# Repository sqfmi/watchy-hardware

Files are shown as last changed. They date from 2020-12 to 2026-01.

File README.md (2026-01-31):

# Watchy - Hardware Source Files

Watchy

**Buy Watchy from [The Pi Hut](https://thepihut.com/collections/sqfmi), [Crowd Supply](https://www.crowdsupply.com/sqfmi/watchy), and [Mouser](https://www.mouser.com/ProductDetail/SQFMI/SQFMI-WATCHY-10?qs=DRkmTr78QARN9VSJRzqRxw%3D%3D)!**

[**Watchy Case & Accessories**](https://shop.sqfmi.com)

Visit [**https://watchy.sqfmi.com**](https://watchy.sqfmi.com) to get started!

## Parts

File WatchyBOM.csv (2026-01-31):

Id | Designator | Footprint | Quantity | Designation | Supplier and ref
1 | Q3 | SOT-23 | 1 | AO3400A
2 | L2 | L_Taiyo-Yuden_NR-40xx | 1 | 47uH 0.5A
3 | D5,D4,D3 | D_SOD-123 | 3 | MBR0530
4 | R17 | R_0402_1005Metric | 1 | 2.2
5 | C21,C20 | C_0603_1608Metric | 2 | 4.7uF/50V
6 | U3 | SOT-23-5 | 1 | TP4054
7 | R16 | R_0402_1005Metric | 1 | 1M
8 | J1 | 1.25T-2PWT (Molex 532610271) | 1 | Battery
9 | J3 | 24_Pins_0.5mm_Pitch_ZIF_Connector_UP | 1 | FPC24(0.5MM)
10 | M1 | Motor_Header | 1 | Vibration_Motor
11 | J2 | USB_Micro-B | 1 | Micro USB
12 | G*** | sqfmi_duck | 1 | LOGO
13 | C29,C25,C27,C22,C23,C24,C28,C26 | C_0402_1005Metric | 8 | 1uF/50V
14 | C3,C2,C15,C4 | C_0402_1005Metric | 4 | 1uF
15 | R4,R2,R15,R8,R11,R6,R19,R7,R10 | R_0402_1005Metric | 9 | 100K
16 | Y2 | Crystal_SMD_2520-4Pin_2.5x2.0mm | 1 | 40MHz
17 | TP5 | TestPoint_Pad_D1.0mm | 1 | GND
18 | SW1 | EVQPUC | 1 | BTN2
19 | C6,C5,C11,C14,C12,C13 | C_0402_1005Metric | 6 | 100nF
20 | C10,C1 | C_0402_1005Metric | 2 | 10uF
21 | R13 | R_0402_1005Metric | 1 | 1K
22 | L1 | L_0402_1005Metric | 1 | TBD
23 | Q2 | SOT-23 | 1 | S8050
24 | U4 | QFN-56-1EP_7x7mm_P0.4mm_EP5.6x5.6mm | 1 | ESP32-S3
25 | R18,R3,R1,R20 | R_0402_1005Metric | 4 | 10K
26 | R5,R14 | R_0402_1005Metric | 2 | 51K
27 | TP6 | TestPoint_Pad_D1.0mm | 1 | SCL
28 | SW2 | EVQPUC | 1 | BTN1
29 | TP2 | TestPoint_Pad_D1.0mm | 1 | RX
30 | C9,C7 | C_0402_1005Metric | 2 | TBD
31 | Q1 | SOT-23 | 1 | CJ2301
32 | U6 | LGA-12_2x2mm_P0.5mm | 1 | BMA423
33 | AE1 | SWRA117D | 1 | Antenna_Chip
34 | TP1 | TestPoint_Pad_D1.0mm | 1 | TX
35 | C16,C19 | C_0402_1005Metric | 2 | 22pF
36 | SW3 | EVQPUC | 1 | BTN3
37 | U2 | SOT-23-5 | 1 | RT908033
38 | TP7 | TestPoint_Pad_D1.0mm | 1 | SDA
39 | R9 | R_0402_1005Metric | 1 | 360K
40 | D2 | D_SOD-123F | 1 | 1N4001
41 | C18,C17 | C_0402_1005Metric | 2 | 18pF
42 | TP3 | TestPoint_Pad_D1.0mm | 1 | BOOT
43 | U5 | SOT-666 | 1 | USBLC6-2P6
44 | TP4 | TestPoint_Pad_D1.0mm | 1 | 3V3
45 | R12 | R_0402_1005Metric | 1 | TBD
46 | SW4 | EVQPUC | 1 | BTN4
47 | U1 | SR2HARU | 1 | SR2HARU
48 | D1 | D_SOD-123 | 1 | MBR0530
49 | Y1 | Crystal_SMD_2012-2Pin_2.0x1.2mm | 1 | 32.768KHz

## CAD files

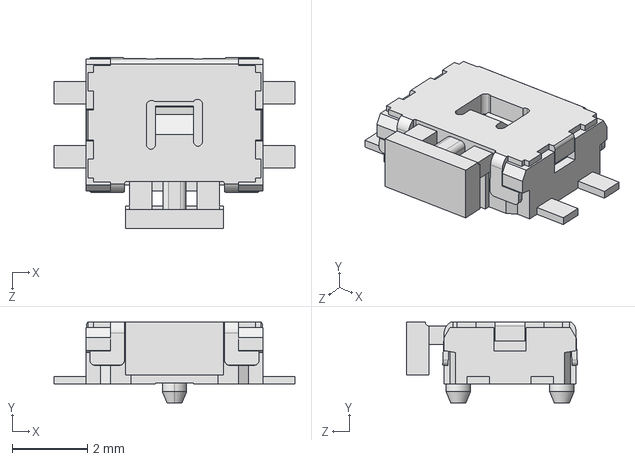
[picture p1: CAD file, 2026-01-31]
3D/EVQPU-LC-02K.STEP
6.40 x 2.15 x 4.54 mm

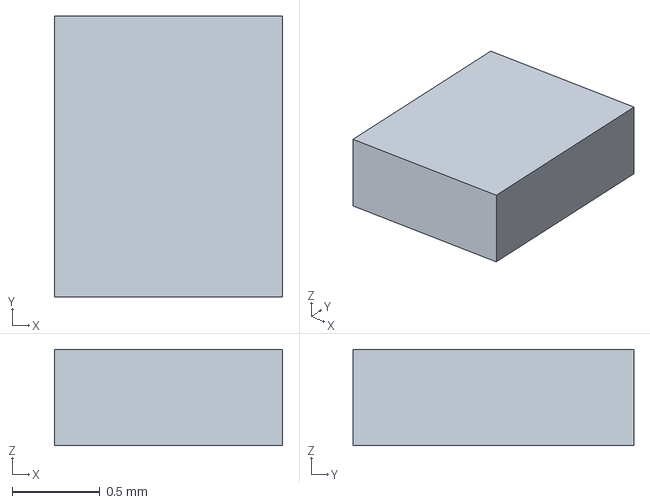
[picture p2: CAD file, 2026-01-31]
3D/UDFN6_16x13.step
1.30 x 1.60 x 0.55 mm

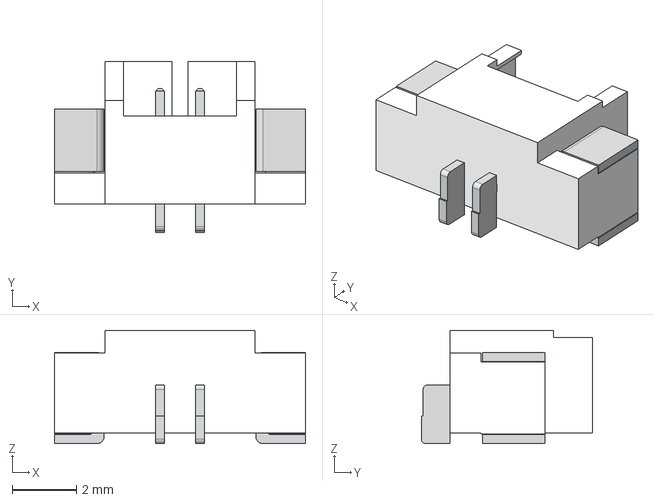
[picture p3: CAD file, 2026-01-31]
3D/JST - SMD (R) - 2Pin - 1.25mm.step
7.83 x 5.35 x 3.53 mm

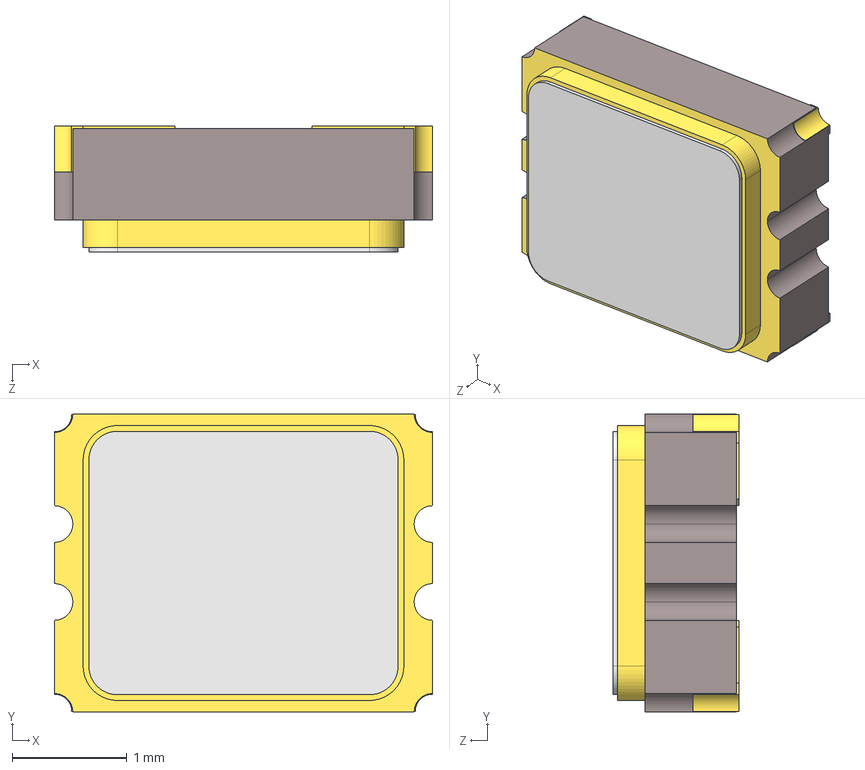
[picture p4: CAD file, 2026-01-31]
3D/Crystal_4pin_2520.STEP
3.30 x 2.60 x 1.10 mm
ASTX_Pad
ASTX_Pad001
ASTX_Pad002
ASTX_ComponentPads

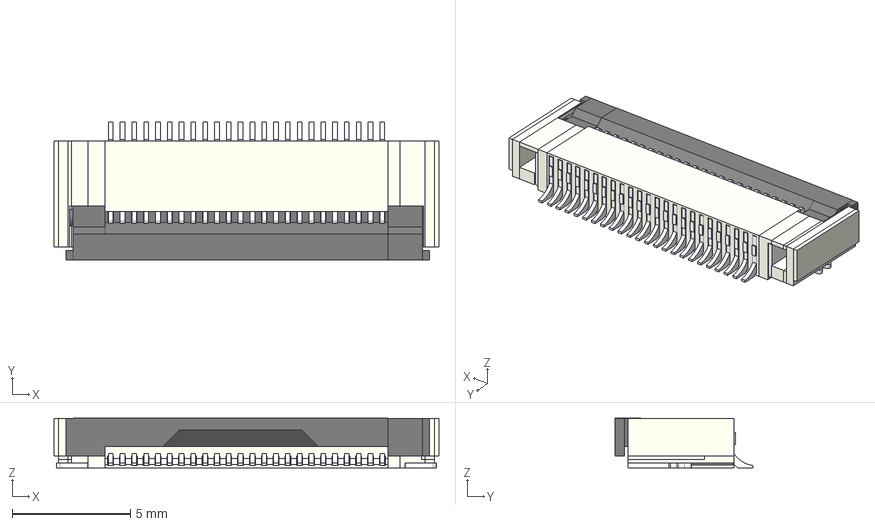
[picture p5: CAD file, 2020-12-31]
3D/FPC-24.stp
16.3 x 5.85 x 2.11 mm

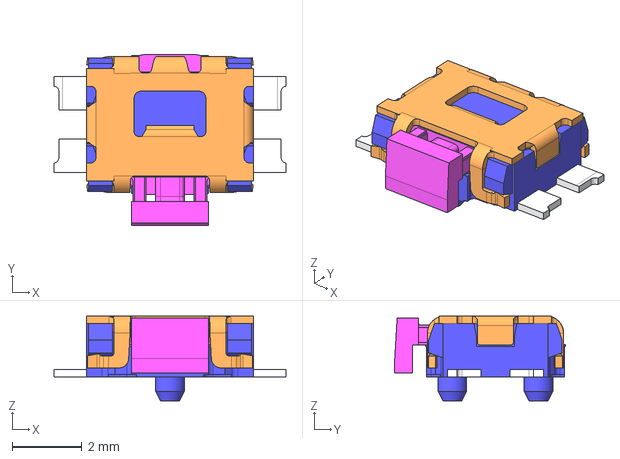
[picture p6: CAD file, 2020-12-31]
3D/Button.step
6.65 x 4.89 x 2.43 mm

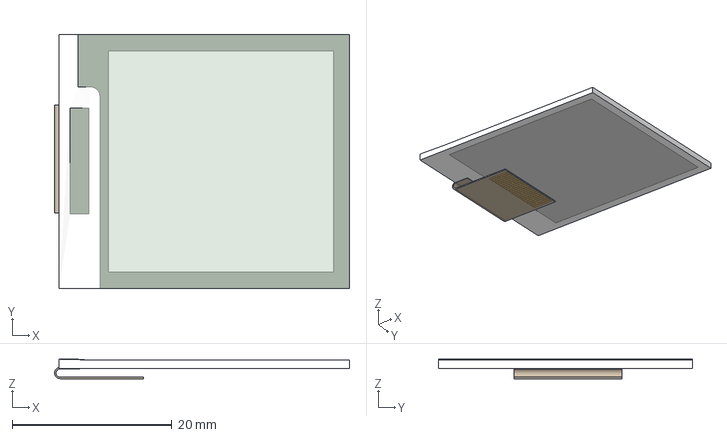
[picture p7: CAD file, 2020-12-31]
3D/Display.step
36.9 x 31.8 x 2.45 mm

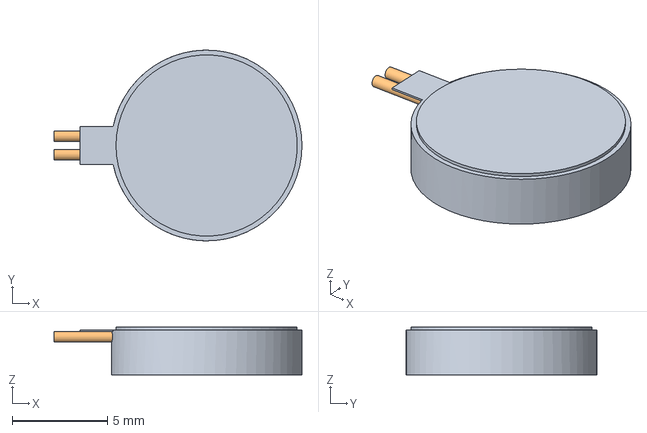
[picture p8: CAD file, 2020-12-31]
3D/PagerMotor.STEP
13.0 x 10.00 x 2.50 mm

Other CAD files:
3D/Battery402030.step

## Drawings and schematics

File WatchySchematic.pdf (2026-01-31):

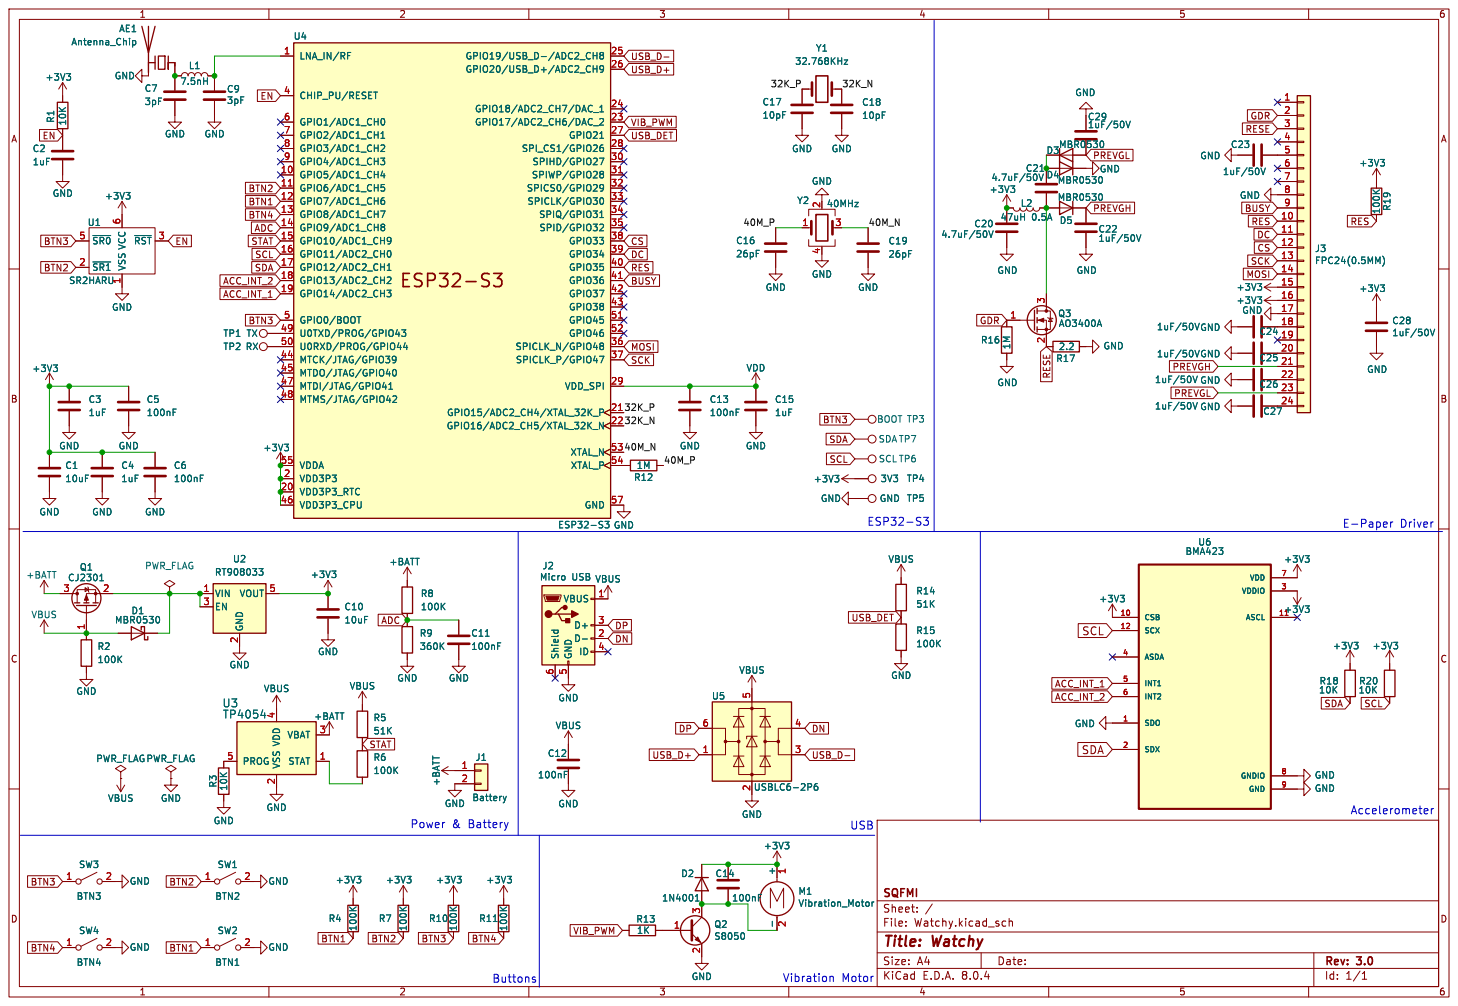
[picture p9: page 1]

File: Watchy.kicad_sch Sheet: / SQFMI GND

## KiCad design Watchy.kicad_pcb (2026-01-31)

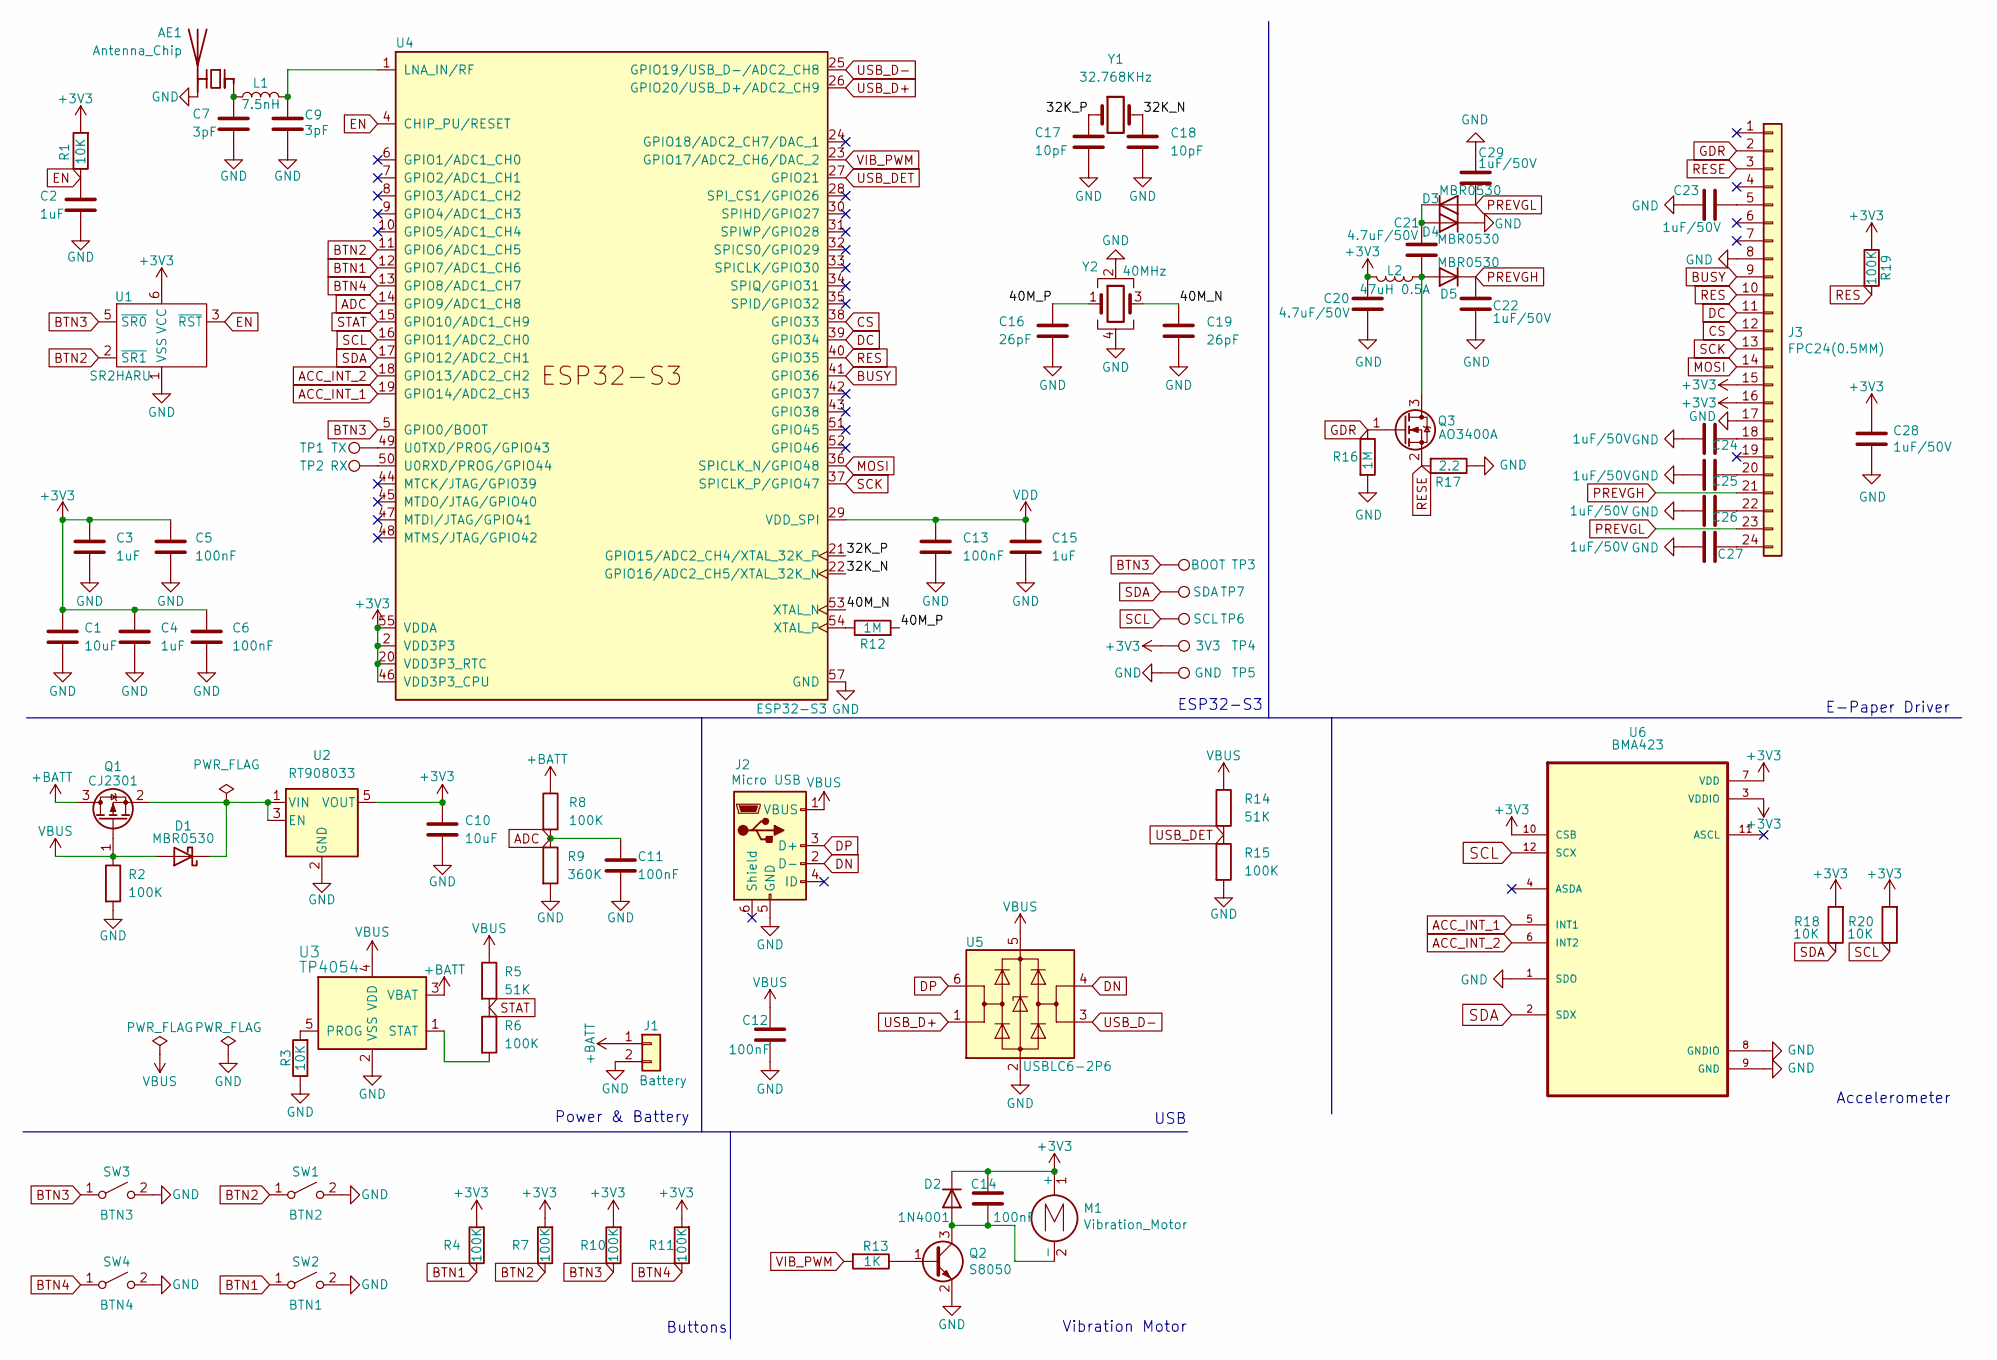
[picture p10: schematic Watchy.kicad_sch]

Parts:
AE1: Antenna_Chip; SWRA117D
C1, C10: 10uF; C_0402_1005Metric
C2, C3, C4, C15: 1uF; C_0402_1005Metric
C5, C6, C11, C12, C13, C14: 100nF; C_0402_1005Metric
C7, C9: 3pF; C_0402_1005Metric
C16, C19: 26pF; C_0402_1005Metric
C17, C18: 10pF; C_0402_1005Metric
C20, C21: 4.7uF/50V; C_0603_1608Metric
C22, C23, C24, C25, C26, C27, C28, C29: 1uF/50V; C_0402_1005Metric
D1, D3, D4, D5: MBR0530; D_SOD-123
D2: 1N4001; D_SOD-123F
J1: Battery; 1.25T-2PWT (Molex 532610271)
J2: Micro USB; USB_Micro-B
J3: FPC24(0.5MM); 24_Pins_0.5mm_Pitch_ZIF_Connector_UP
L1: 7.5nH; L_0402_1005Metric
L2: 47uH 0.5A; L_Taiyo-Yuden_NR-40xx
M1: Vibration_Motor; Motor_Header
Q1: CJ2301; SOT-23
Q2: S8050; SOT-23
Q3: AO3400A; SOT-23
R1, R3, R18, R20: 10K; R_0402_1005Metric
R2, R4, R6, R7, R8, R10, R11, R15, R19: 100K; R_0402_1005Metric
R5, R14: 51K; R_0402_1005Metric
R9: 360K; R_0402_1005Metric
R12, R16: 1M; R_0402_1005Metric
R13: 1K; R_0402_1005Metric
R17: 2.2; R_0402_1005Metric
SW1: BTN2; EVQPUC
SW2: BTN1; EVQPUC
SW3: BTN3; EVQPUC
SW4: BTN4; EVQPUC
TP1: TX; TestPoint_Pad_D1.0mm
TP2: RX; TestPoint_Pad_D1.0mm
TP3: BOOT; TestPoint_Pad_D1.0mm
TP4: 3V3; TestPoint_Pad_D1.0mm
TP5: GND; TestPoint_Pad_D1.0mm
TP6: SCL; TestPoint_Pad_D1.0mm
TP7: SDA; TestPoint_Pad_D1.0mm
U1: SR2HARU
U2: RT908033; SOT-23-5
U3: TP4054; SOT-23-5
U4: ESP32-S3; QFN-56-1EP_7x7mm_P0.4mm_EP5.6x5.6mm
U5: USBLC6-2P6; SOT-666
U6: BMA423; LGA-12_2x2mm_P0.5mm
Y1: 32.768KHz; Crystal_SMD_2012-2Pin_2.0x1.2mm
Y2: 40MHz; Crystal_SMD_2520-4Pin_2.5x2.0mm

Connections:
+3V3: C1.1, C3.1, C4.1, C5.1, C6.1, C10.1, C14.1, C20.1, C28.1, D2.1 (K), J3.15, J3.16, L2.2, M1.1 (+), R1.2, R4.2, R7.2, R10.2, R11.2, R18.2, R19.1, R20.2, TP4.1, U1.6 (VCC), U2.5 (VOUT), U4.2 (VDD3P3), U4.3 (VDD3P3), U4.20 (VDD3P3_RTC), U4.46 (VDD3P3_CPU), U4.55 (VDDA), U4.56 (VDDA), U6.3 (VDDIO), U6.7 (VDD), U6.10 (CSB); also elsewhere on the board
+BATT: J1.1, Q1.3 (D), R8.1, U3.3 (VBAT)
/32K_N: C18.1, U4.22 (GPIO16/ADC2_CH5/XTAL_32K_N), Y1.2
/32K_P: C17.1, U4.21 (GPIO15/ADC2_CH4/XTAL_32K_P), Y1.1
/40M_N: C19.1, U4.53 (XTAL_N), Y2.3
/40M_P: C16.1, R12.2, Y2.1
ACC_INT_1: U4.19 (GPIO14/ADC2_CH3), U6.5 (INT1)
ACC_INT_2: U4.18 (GPIO13/ADC2_CH2), U6.6 (INT2)
ADC: C11.1, R8.2, R9.1, U4.14 (GPIO9/ADC1_CH8)
BTN1: R4.1, SW2.1 (A), U4.12 (GPIO7/ADC1_CH6)
BTN2: R7.1, SW1.1 (A), U1.2 (~SR1), U4.11 (GPIO6/ADC1_CH5)
BTN3: R10.1, SW3.1 (A), TP3.1, U1.5 (~SR0), U4.5 (GPIO0/BOOT)
BTN4: R11.1, SW4.1 (A), U4.13 (GPIO8/ADC1_CH7)
BUSY: J3.9, U4.41 (GPIO36)
CS: J3.12, U4.38 (GPIO33)
DC: J3.11, U4.39 (GPIO34)
DN: J2.2 (D-), U5.4 (I/O2)
DP: J2.3 (D+), U5.6 (I/O1)
EN: C2.1, R1.1, U1.3 (~RST), U4.4 (CHIP_PU/RESET)
GDR: J3.2, Q3.1 (G), R16.1
GND: AE1.2 (PCB_Trace), C1.2, C2.2, C3.2, C4.2, C5.2, C6.2, C7.2, C9.2, C10.2, C11.2, C12.2, C13.2, C15.2, C16.2, C17.2, C18.2, C19.2, C20.2, C22.2, C23.2, C24.2, C25.2, C26.2, C27.2, C28.2, C29.1, D4.1 (K), J1.2, J2.5 (GND), J3.8, J3.17, Q2.2 (E), R2.2, R3.1, R9.2, R15.2, R16.2, R17.1, SW1.2 (B), SW2.2 (B), SW3.2 (B), SW4.2 (B), TP5.1, U1.1 (VSS), U2.2 (GND), U3.2 (VSS), U4.57 (GND), U5.2 (GND), U6.1 (SDO), U6.8 (GNDIO), U6.9 (GND), Y2.2, Y2.4; also elsewhere on the board
MOSI: J3.14, U4.36 (SPICLK_N/GPIO48)
unnamed: AE1.1 (FEED), C7.1, L1.1
unnamed: D1.1 (K), Q1.2 (S), U2.1 (VIN), U2.3 (EN)
unnamed: C14.2, D2.2 (A), M1.2 (-), Q2.3 (C)
unnamed: C21.1, D3.1 (K), D4.2 (A)
unnamed: C21.2, D5.2 (A), L2.1, Q3.3 (D)
unnamed: C23.1, J3.5
unnamed: C24.1, J3.18
unnamed: C25.1, J3.20
unnamed: C26.1, J3.22
unnamed: C27.1, J3.24
unnamed: Q2.1 (B), R13.1
unnamed: R3.2, U3.5 (PROG)
unnamed: R6.2, U3.1 (STAT)
unnamed: C9.1, L1.2, U4.1 (LNA_IN/RF)
unnamed: TP2.1, U4.50 (U0RXD/PROG/GPIO44)
unnamed: TP1.1, U4.49 (U0TXD/PROG/GPIO43)
unnamed: R12.1, U4.54 (XTAL_P)
PREVGH: C22.1, D5.1 (K), J3.21
PREVGL: C29.2, D3.2 (A), J3.23
RES: J3.10, R19.2, U4.40 (GPIO35)
RESE: J3.3, Q3.2 (S), R17.2
SCK: J3.13, U4.37 (SPICLK_P/GPIO47)
SCL: R20.1, TP6.1, U4.16 (GPIO11/ADC2_CH0), U6.12 (SCX)
SDA: R18.1, TP7.1, U4.17 (GPIO12/ADC2_CH1), U6.2 (SDX)
STAT: R5.2, R6.1, U4.15 (GPIO10/ADC1_CH9)
USB_D+: U4.26 (GPIO20/USB_D+/ADC2_CH9), U5.1 (I/O1)
USB_D-: U4.25 (GPIO19/USB_D-/ADC2_CH8), U5.3 (I/O2)
USB_DET: R14.2, R15.1, U4.27 (GPIO21)
VBUS: C12.1, D1.2 (A), J2.1 (VBUS), Q1.1 (G), R2.1, R5.1, R14.1, U3.4 (VDD), U5.5 (VBUS)
VDD: C13.1, C15.1, U4.29 (VDD_SPI)
VIB_PWM: R13.2, U4.23 (GPIO17/ADC2_CH6/DAC_2)

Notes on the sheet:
Vibration Motor
Buttons
E-Paper Driver
Accelerometer
ESP32-S3
USB
Power & Battery

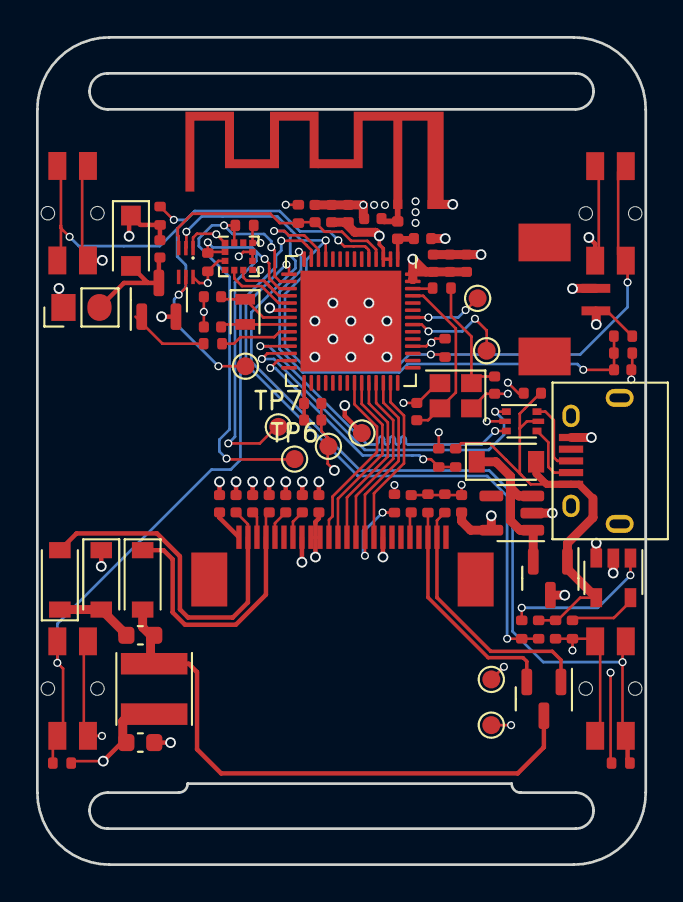
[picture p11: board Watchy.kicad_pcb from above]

Board: 4 copper layers, 33.8 x 46.0 mm, 84 parts (0 on the bottom side), 53 nets.

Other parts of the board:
TP4#2: 3V3; TestPoint_Pad_D1.0mm
TP5#2: GND; TestPoint_Pad_D1.0mm

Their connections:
+3V3: TP4#2.1; also elsewhere on the board
GND: TP5#2.1; also elsewhere on the board

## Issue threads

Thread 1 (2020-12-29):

Missing 3D models?

jdarpinian, 2020-12-29:
I'm new to kicad, so forgive me if I'm missing something, but it seems like the project references at least one 3D model that's not included in the repo here, ${KIPRJMOD}/3D/PagerMotor.STEP. Also the latest kicad libraries (https://github.com/kicad/kicad-packages3d) do not include ${KISYS3DMOD}/Button_Switch_SMD.3dshapes/SKSCLB.STEP or Capacitors_SMD.3dshapes/C_0603.wrl among others. Do I need to install extra libraries, or use a different version of kicad (currently 5.1.9)?

sqfmi, 2020-12-31:
Updated project to reference correct models, should work with current version of KiCad

jdarpinian, 2021-01-01:
Awesome! Thanks!

Closed 2021-01-01.

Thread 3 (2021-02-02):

Missing 32KHz oscillator for Low-Power BLE connectivity

LeonMatthes, 2021-02-02:
As mentioned in [this issue](https://github.com/espressif/esp-idf/issues/947 ), BLE with light sleep on the ESP32 is currently only supported with the use of an external 32KHz oscillator.

Unfortunately, Watchy currently does not have this, which is going to make it very difficult to maintain a true low power Bluetooth connectivity to a smartphone. For me this is a major use case for a smart watch...

Even more unfortunate is that the RTC can provide the exact waveform needed at its 32KHz output pin, however, it's not connected to the right pin of the ESP (GPIO 32_XP). And the pin is already used for BTN_3. (At least I think, I'm not a Hardware expert).

Maybe this could be fixed in a new revision of the Watchy hardware (perhaps even in the crowd supply campaign :pray: ).

m986883511, 2021-02-08:
I also have this problem，我用的的是现成的ESP32-WRROOM-32模块，没法加32k的晶振，这个是个不错的想法，希望得到乐鑫的解答。

LeonMatthes, 2021-02-10:
After looking at the ESP32 Hardware reference manual, I just wanted to add that the input pin for the 32KHz waveform might have to be the 32_XN (IO33) pin, and 32_XP might need to be connected to ground through a capacitor, but I'm not certain on this.
It would just be amazing to see the 2mA power consumption with BLE active that can be seen in the prior thread!

Jan-NiklasB, 2021-03-25:
If the devs don't see any problems with the changes, this should fix it: #5

Jan-NiklasB, 2021-03-25:
NVM, have to do it over again, LeonMatthes is right with the assumption that the source has to be connected to 32K_X**N** and a capacitor has to be placed between GND and 32K_XP...

sqfmi, 2021-03-25:
@Jan-NiklasB also it is recommended the signal amplitude be 0.6 < Vpp < VDD. We actually have a layout we're testing before we publish, so this might save you some time...

LeonMatthes, 2021-12-16:
From recent discussion on Discord it seems this is now part of the new board design.
@sqfmi can you confirm?
And has anyone tried it? Can you keep BLE active during light sleep?

This might seriously be a reason for me to get a newer version.

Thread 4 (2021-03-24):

[Feature request] Pulse-oxymeter

Jan-NiklasB, 2021-03-24:
Hey guys,

I just stumbled over this project looking for a possible smart watch candidate to buy (should be OHW / OS).
I'm a fan of the ESP32 uC, so this project has a greate potetial in my opinion, but looking at the most other smart watches out there I'm personally missing a pulse-oxymeter (heart rate + SpO2 sensor).

So I want to suggest include such sensor in a future version of this project.
Those sensors are getting more and more tiny, so I guess such a chp could may be added to the PCB.

I would be interested in your thoughts about this idea.

Greetings
Jan-Niklas

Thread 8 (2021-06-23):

[Feature Request] NFC

aceggroll, 2021-06-23:
For next revision, can you add NFC components. (eg https://www.nxp.com/docs/en/nxp/data-sheets/PN532_C1.pdf)
Could then use Watchy with other NFC devices, eg  https://arduinogetstarted.com/tutorials/arduino-rfid-nfc-door-lock-system
Happy to be first to sign up on CrowdSupply!

danShumway, 2021-07-22:
I'll also throw out a vote for NFC. Would really open some doors for using the device in interesting ways I think, considering how cheap NFC tags are.

I'm sticking tags up around my house for triggering actions with my phone, but I don't always carry my phone. I will almost always have a watch on though, so Watchy would be just completely perfect for something like this.

adapt-L, 2024-08-04:
It would be cool if watchy had this capability. But what antenna would this require? I was looking at how Flipper Zero implemented NFC and RFID, and it seems like it might require a large circuit board to act as the antenna.

adapt-L, 2024-08-04:
But yeah, it would be really nice to use watchy as a wireless-swiss-army-knife like Flipper Zero (You can use it to clone your NFC/RFID cards). It already has the hardware to compete with products like https://dstike.com/products/dstike-deauther-watch-v3s

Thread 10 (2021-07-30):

[Feature request] Beeps/sound

denizzzka, 2021-07-30:

adapt-L, 2024-08-04:
I just got the new one, and it has a vibration motor if that meets your needs

denizzzka, 2024-08-04:
Oh, finally I waited! :-)

Closed 2024-08-04.

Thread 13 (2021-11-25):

New PCB revision released with no documentation

miekush, 2021-11-25:
Recently I purchased a [Watchy from Mouser](https://www.mouser.com/ProductDetail/SQFMI/SQFMI-WATCHY-10?qs=DRkmTr78QARN9VSJRzqRxw%3D%3D) and I noticed some issues with time not updating using the example watch faces. After some debugging I noticed the PCB shown in the documentation and hardware design files differed from my board. It appears a new version has been released which has replaced the previous DS3231 RTC with a [PCF8563](https://www.nxp.com/docs/en/data-sheet/PCF8563.pdf). Unfortunately it seems this repo, the SW library and all of the user documentation has not been updated.

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

filipproch, 2021-11-30:
@miekush not sure if you are on Discord, so sharing here as well
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

sqfmi, 2021-12-25:
Sorry for the delay, pushed to v1.5

miekush, 2021-12-25:
No worries! Thank you.

Closed 2021-12-25.

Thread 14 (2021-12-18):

Display RST circuit should be pulled up

DarkZeros, 2021-12-18:
Hi, as part of my developments to get Watchy low power (and solar). https://github.com/sqfmi/Watchy/issues/118
I found out that there were inconsistent power usages in the display module.

Just "touching" the connector would lead to differences in power usage from 130uA-600uA.
Also different displays seem to behave differently (V1-V2, color, ...). Agains same range 130uA-600uA.

I ended up finding that the RES# pin was the culprit, just touching that one would change the results.
RES# of the display is supposed to be left connected to HIGH.
If it is not left in that state the Dsiplay hardware will not fully enter deep sleep.

I checked that with ANY display and any watchy (I have 2), leaving this pin to 3V3 sets the power usage to 125uA.

The problem is, it can't be done on SW, since the RES pin is connected to a normal GPIO and not to a RTC GPIO.
GPIOs are left high impedance in deep sleep and therefore not driven to any value.
Solutions:
- Pullup resistor of 100k-1M (I measured no current flowing in the pin at all <1uA).
- Connect RES to RTC pin and leave the PIN as output + HIGH state.

DarkZeros, 2021-12-18:
I can confirm that a 1M resistor to 3V3 fixes the problem! (On v1.0 HW)

sqfmi, 2021-12-24:
This is great! We'll add this fix in the next HW revision!

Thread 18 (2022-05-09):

The USB-Serial chip is CP2102N, isn't it CP2102?

mori-oh, 2022-05-09:
USB serial communication with Watchy did not work and I saw the circuit.
In the Rev2.0 schematic, CP2104 is replaced with "CP2102", but it looks like CP2102N because it has 24 pins (CP2102 is QFN28, isn't it?).
Also, Silabs documentation AN976 tells you to use a resistor divider when replacing CP2104 with CP2102N and should be fixed.

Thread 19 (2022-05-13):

Support USB power and charging status on GPIO pins

synthead, 2022-05-13:
When Watchy hardware is plugged in, the OS has no introspection on if the device is currently being charged, or if it's connected to USB power.

In the KiCad project, TP4054 (the Li-Po charging controller) already has an LED indicator when the device is being charged:

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

This illuminates when charging, and stops illuminating when the battery is fully charged.  When charging, TP4054 STAT (pin 1) appears to be low-impedance and pulls its input to Vss, and when not charging, this input appears to be high-impedance.  This means that current can attempt to flow into its input, but it doesn't have enough resistance to illuminate the LED.

This behavior can easily be adapted to be used with a GPIO by pulling STAT high and connecting it to an unused GPIO input on the ESP32.  When the LED illuminates, STAT will pull the signal low, and this can be used to reliably tell the Watchy that we're charging.

For the "charger connected" indicator, we can simply connect VBUS to an unused GPIO pin.  This pin can be pulled low.  The LED is a diode at heart, so if a pull-up resistor comes after it, there shouldn't be any meaningful current passing though it, and it should not illuminate.

Here is the ESP32-PICO-D4 IC with its unused GPIO pins highlighted:

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

We'll also want to ensure that these two inputs have some kind of circuit protection, and that the signals are converted to 3.3V.  There are many good answers to solving this.  Even a little current-limiting resistor paired with a 3.1V zener diode should do the trick nicely.

With Watchy having some insight to its own charging hardware, in addition to a better battery and charging icons, we can also do interesting things like battery self-calibration to accommodate for battery wear.  As batteries age, the amount of energy they store lessens, and that results in less voltage being stored in the cells.  By reading raw voltage over an ADC without calibration (the current state of things), a worn cell may state: "I am fully charged at 60%."  While accurate, this is not typically how charged worn cells are presented, which incurs UX issues.  Users are used to seeing "I plugged it in until it went to 100%."

When a battery becomes fully charged (as indicated by TP4054) and USB power is still present, we know that the battery became fully charged.  If the above is implemented, the charging pin will go high, and we can immediately call whatever voltage is present the "100%" mark.  This can be put into EEPROM so that this calibration can survive reboots.  Additionally, we can do the same with a dying battery: when calibrating, write the ADC value to EEPROM until the device shuts off on its own.  When given USB power again, the OS will correctly know what "0%" is.

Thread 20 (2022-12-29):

Accelerometer needs pin 10 connected to VDD

SamCooper, 2022-12-29:
The current pin allocation for the BMA423 has pin 10 left floating but it should be connected to +3.3 to avoid the potential of the device switching to SPI interface.

This is according to the datasheet from Bosch.

sqfmi, 2023-06-30:
Thanks! This change will be in the next rev

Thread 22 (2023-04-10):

USB-C

MichalLebeda, 2023-04-10:
It would be great to use more durable USB-C. The downside is that it would make all the existing cases obsolete. On the other hand it is better to do sooner than later, as all the devices are migrating to type C currently.

onionhammer, 2023-06-10:
I was about to post this independently, I ordered this but definitely holding my nose about the micro USB

adapt-L, 2024-08-04:
I concur with OP. microUSB is very fragile and USB-C has quickly become the standard. Perhaps it is possible to retrofit boards by soldering something like this https://www.youtube.com/watch?v=V-vFtiDYiIw but this is a lot of extra work for the end user.

adapt-L, 2024-08-04:
> I would need to modify the device's port and maybe even the circuitry to accommodate the new connector's dimensions and functionalities. I would also like MichalLebeda mentioned need to change the case...

You wouldn't need to modify the circuit board. If you are worried about spacing, you could solder on some wires and install the new port on the other side of the board. I think it will likely require a case redesign though, which is fine because I was planning on making a custom case anyways. I have a soldering iron so I might try retrofitting it after I am done experimenting with the software.

lealife, 2025-04-22:
https://github.com/xywatch/watchy-hardware-v2 fix it

CuiYao631, 2025-05-11:
> https://github.com/xywatch/watchy-hardware-v2修复它

I’m glad to see that someone has made a USB-C version. I will try using your version.

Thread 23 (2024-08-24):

[reality check] should pins 13 and 14 on the display connector be shorted?

shtrom, 2024-08-24:
tl;dr: should pins 13 (SCK) and 14 (MOSI) on the [display connector (J1)](https://github.com/sqfmi/watchy-hardware/blob/main/WatchySchematic.pdf) be shorted?

The buttons on my Watchy died, so I set out to replace them with Wurth Elektronik 436351045816 436351045816 from Mouser (https://github.com/sqfmi/Watchy/issues/49#issuecomment-2308150293). That worked, and I can get a program running on the watch that confirms they are functional.

But my display no longer refreshes. So I suspect I might have damaged something else when desoldering/resoldering. When testing the display connector, I noticed that pin 13 (SCK) and 14 (MOSI) are shorted. Should this be the case, or is this what I need to fix?

etwasmitbaum, 2024-08-26:
SCK and MOSI are pins needed for SPI communication, so they should not be shorted.
Since both are outputs, the GPIO pins on the ESP32 could be dead.
You could get lucky and both still work.
Remove the short and try again.
Good luck

shtrom, 2024-08-26:
Cool, thanks for this!

They are not explicitely shorted, but when I test them, there is 0 ohm between them; so, a short.

At least I'm on the right investigative path. I'll see how I can test those pins.

Thanks!

shtrom, 2024-10-06:
Ok, more on this. I think I was counting wrong, and was instead looking at pins 15 and 16 which... are both +3V3, so it makes sense they measure as a short.

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

shtrom, 2024-10-21:
Conclusion: I ordered a replacement eInk display from Good Display, and that worked. My issue was that I somehow borked the display.

Closed 2024-10-06.

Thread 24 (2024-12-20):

Connection for wireless charger

medisoft, 2024-12-20:
Hi! I suggest to add a pair of pins for a wireless charger. I bought this ([round](https://es.aliexpress.com/item/1005004482691660.html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) version) Qi charger at ali express, and connected the battery to the battery section of the charger, and also connected the same port with another wire to the battery port on Watchy, and now my Watchy v2.0 charges on any Qi charger!

Including the Apple magsafe and my car.

It would be easier of course, to have a dedicated 1.25mm port for connecting the Qi charger, or better, to add the Qi chip and circuit into the main PCB and put the coil in the bottom protection PCB.

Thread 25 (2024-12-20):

Add a connector for external, touch buttons

medisoft, 2024-12-20:
It would make sense to put some jst 1.25 connectors for the buttons. So we can add a capacitive touch buttons, allowing to build enclosures that are fully water protected.

Maybe also to submerge all the device in transparent resin, making it very water proof!

With the addition of wireless charging and a firmware partition in case of failed OTA, that would make the device a lot more complete!

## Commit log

2020-12-20 Added KiCad Files
    [Watchy.kicad_pcb, Watchy.sch]
2020-12-31 added body step & STL
    [Button.step, Display.step, FPC-24.stp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]
2020-12-31 added battery models
    [Battery402030.step, Watchy_Battery.stl]
2021-05-27 added testpoints
    [Watchy.kicad_pcb, Watchy.sch]
2021-12-25 v1.5
    - switched to new RTC (PCF8563)
    [Watchy-B_Cu.gbr, Watchy-B_Mask.gbr, Watchy-B_Paste.gbr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]
2021-12-25 label CP2102
    CP2102
    [Watchy.sch]
2024-07-24 Add v3 schematic
    [Battery402030.step, Button.step, Display.step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]
2026-01-31 Add files via upload
    file recovery
    [Battery402030.step, Button.step, Crystal_4pin_2520.STEP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]
